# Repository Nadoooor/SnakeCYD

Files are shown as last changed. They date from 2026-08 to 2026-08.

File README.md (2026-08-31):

# SnakeCYD
--------------
<p align="center">
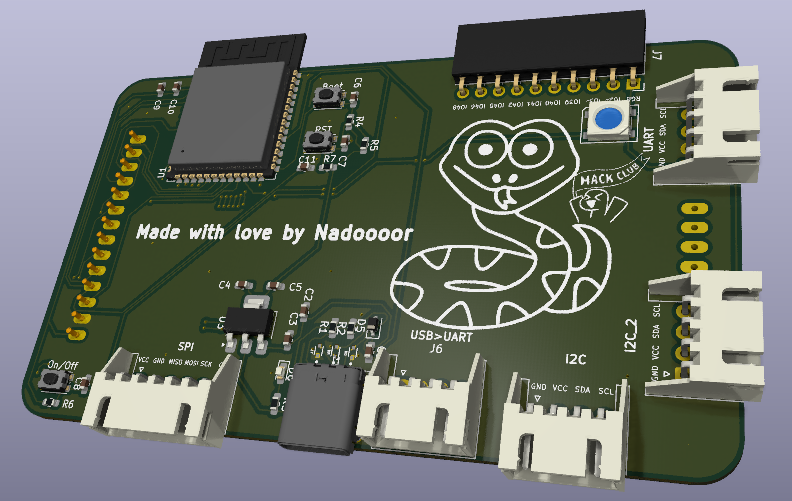
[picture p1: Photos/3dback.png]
Centered Image
  
</p>
--------------------------------

## Description:
SnakeCYD is a custom CYD, all in an PCB with snake slickscreen and with ESP32-s3 instead of a regular ESP32 chip.

## Why iam making this:
I was planning to get a CYD, but I got to know that it has a regular ESP32 on it instead of the S3, so i decided to make my own and add my snake slikscreen and also added bigger connectors for the wiring protocols and also some free pins.

## Featrues:

* Big JST connectors
* Free GPIO with PinSockets
* USB Type C
* Onboard Neopixel
* ESP32-S3 chip inside.

## Photos:

### PCB:
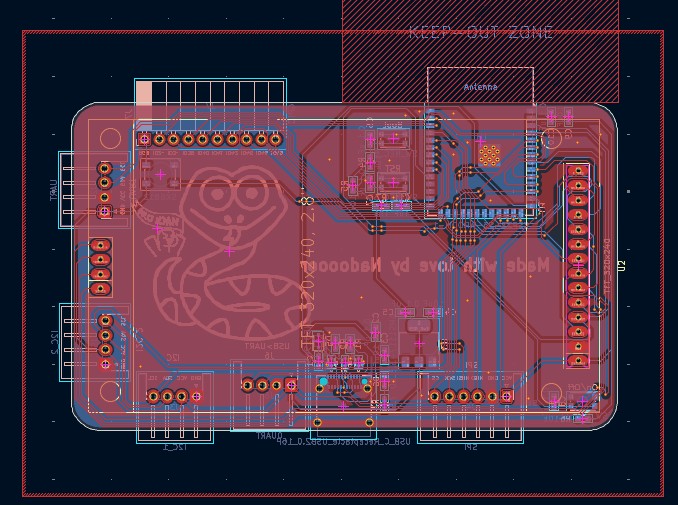
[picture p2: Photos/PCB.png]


### 3D PCB:
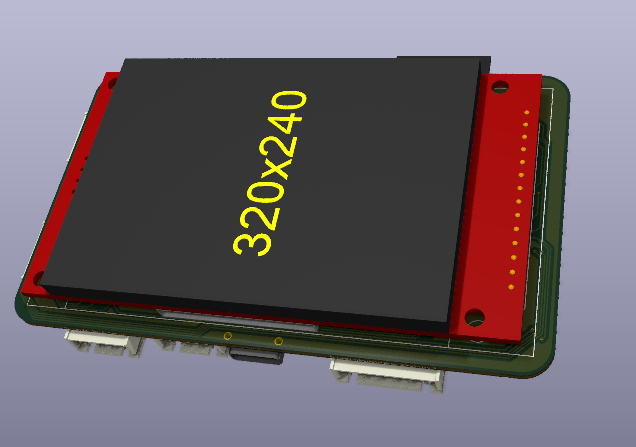
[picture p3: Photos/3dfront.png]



### Schematic:
#### First Page:
--------------------
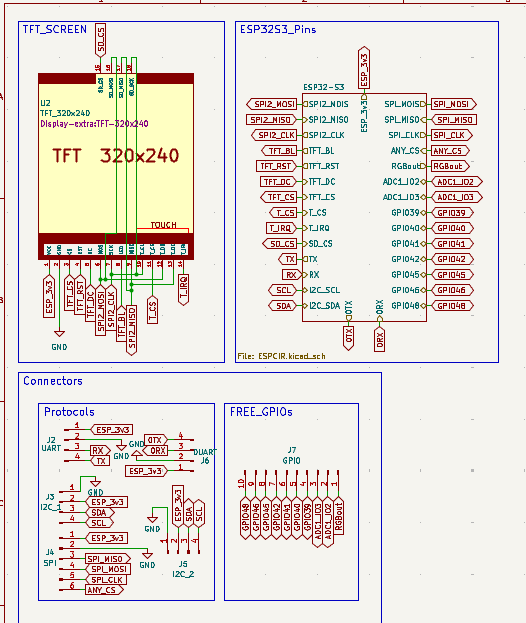
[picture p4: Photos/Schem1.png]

----------------------------
#### Second Page:
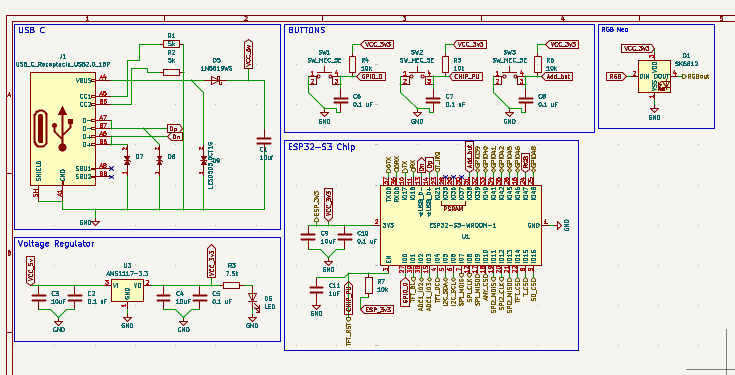
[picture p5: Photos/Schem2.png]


## Pinout:
| ESP32-S3 Pin Label | Signal / Net Name |
| :--- | :--- |
| **IO1** | `TFT_BL` |
| **IO4** | `TFT_DC` |
| **IO5** | `I2C_SDA` |
| **IO6** | `I2C_SCL` |
| **IO7** | `SPI_MOIS` |
| **IO8** | `SPI_CLK` |
| **IO9** | `SPI_MISO` |
| **IO10** | `ANY_CS` |
| **IO11** | `SPI2_MOIS` |
| **IO12** | `SPI2_CLK` |
| **IO13** | `SPI2_MISO` |
| **IO14** | `TFT_CS` |
| **IO15** | `T_CS` |
| **IO16** | `SD_CS` |
| **IO17** | `TX` |
| **IO18** | `RX` |
| **IO21** | `T_IRQ` |
| **TXD0** | `0TX` |
| **RXD0** | `0RX` |

## How to use:
1. Connect the SnakeCYD to you PC/Laptop.
2. Download the firmware source code you want to use.
3. Edit the pinout using the table above.
4. Build the firmware and flash it.
5. Enjoy.

## How to build:
1. Print the board.
2. Assemble all the components.
3. Enjoy.

# Made with ❤️, By Nadoooor

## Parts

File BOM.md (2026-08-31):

| Item | Store | Quantity | PPU | Price |
|---|---|---|-----|---|
| PCBA | JLCPCB | 1 | $94 | $94 |
| Shipping from JLCPCB | JLCPCB | 1 | $30 | $30 |
| TFT screen with SPI and touch 2.8in | [Aliexpress](https://ar.aliexpress.com/item/1005010008924503.html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) | 1 | $10 | $10 |
| Total | ~~~ | ~~~ | ~~~ | $134  |

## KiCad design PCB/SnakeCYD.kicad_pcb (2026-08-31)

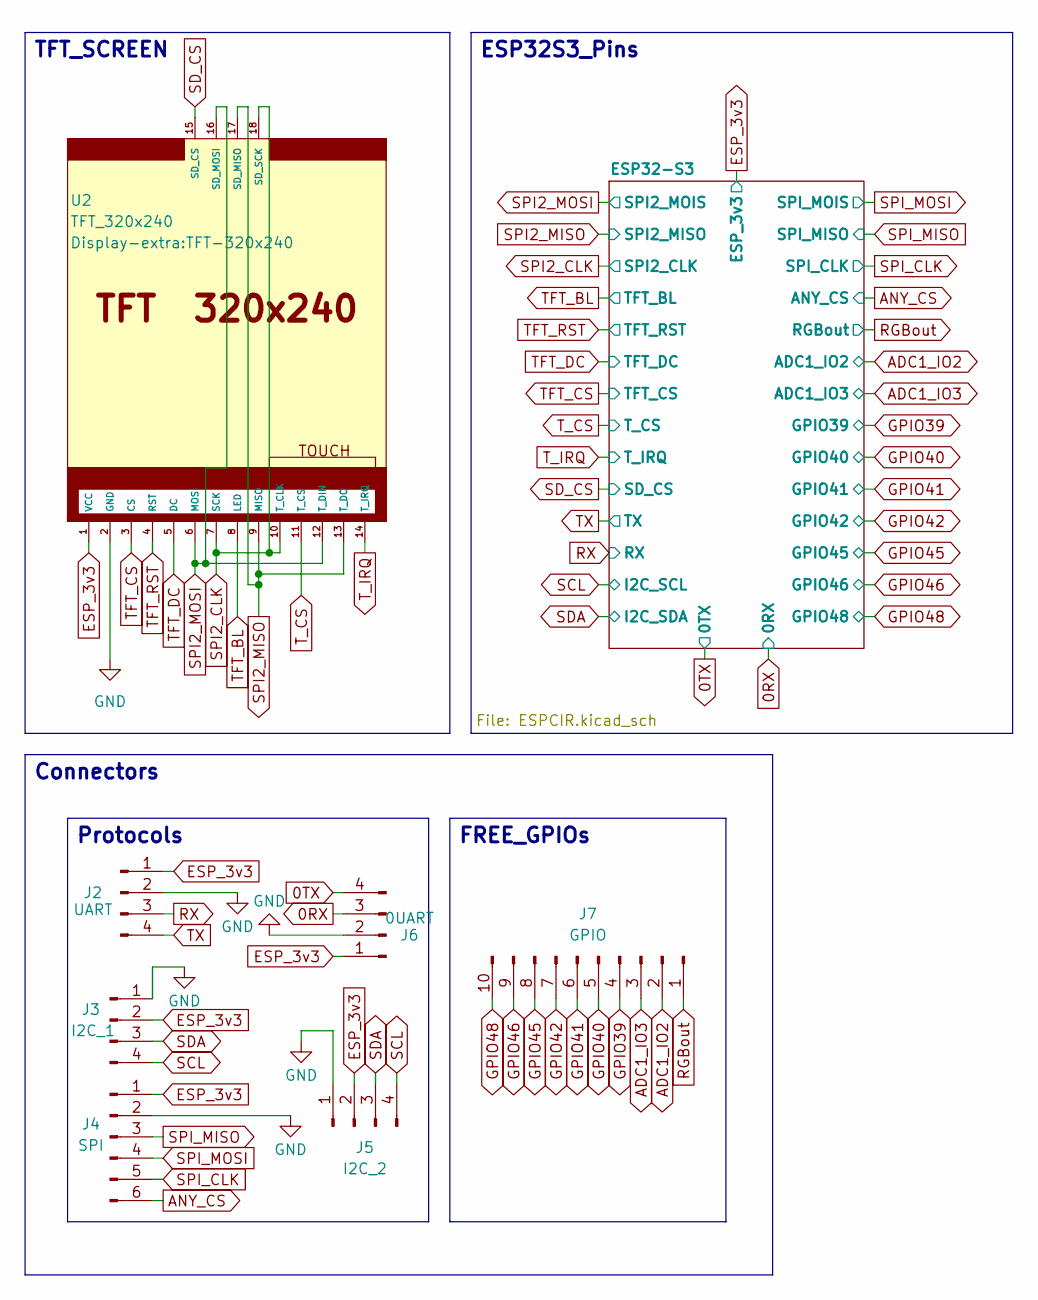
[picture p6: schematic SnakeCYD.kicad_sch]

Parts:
J2: UART; JST_XH_S4B-XH-A-1_1x04_P2.50mm_Horizontal
J3: I2C_1; JST_XH_S4B-XH-A-1_1x04_P2.50mm_Horizontal
J4: SPI; JST_XH_S6B-XH-A-1_1x06_P2.50mm_Horizontal
J5: I2C_2; JST_XH_S4B-XH-A-1_1x04_P2.50mm_Horizontal
J6: 0UART; JST_XH_S4B-XH-A-1_1x04_P2.50mm_Horizontal
J7: GPIO; PinSocket_1x10_P2.54mm_Horizontal
U2: TFT_320x240; TFT-320x240

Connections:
0RX: J6.3; also elsewhere on the board
0TX: J6.4; also elsewhere on the board
ADC1_IO2: J7.2; also elsewhere on the board
ADC1_IO3: J7.3; also elsewhere on the board
ANY_CS: J4.6; also elsewhere on the board
ESP_3v3: J2.1, J3.2, J4.1, J5.2, J6.1, U2.1 (VCC); also elsewhere on the board
GND: J2.2, J3.1, J4.2, J5.1, J6.2, U2.2 (GND); also elsewhere on the board
GPIO39: J7.4; also elsewhere on the board
GPIO40: J7.5; also elsewhere on the board
GPIO41: J7.6; also elsewhere on the board
GPIO42: J7.7; also elsewhere on the board
GPIO45: J7.8; also elsewhere on the board
GPIO46: J7.9; also elsewhere on the board
GPIO48: J7.10; also elsewhere on the board
RGBout: J7.1; also elsewhere on the board
RX: J2.3; also elsewhere on the board
SCL: J3.4, J5.4; also elsewhere on the board
SDA: J3.3, J5.3; also elsewhere on the board
SD_CS: U2.15 (SD_CS); also elsewhere on the board
SPI2_CLK: U2.7 (SCK), U2.10 (T_CLK), U2.18 (SD_SCK); also elsewhere on the board
SPI2_MISO: U2.9 (MISO), U2.13 (T_DO), U2.17 (SD_MISO); also elsewhere on the board
SPI2_MOSI: U2.6 (MOSI), U2.12 (T_DIN), U2.16 (SD_MOSI); also elsewhere on the board
SPI_CLK: J4.5; also elsewhere on the board
SPI_MISO: J4.3; also elsewhere on the board
SPI_MOSI: J4.4; also elsewhere on the board
TFT_BL: U2.8 (LED); also elsewhere on the board
TFT_CS: U2.3 (CS); also elsewhere on the board
TFT_DC: U2.5 (DC); also elsewhere on the board
TFT_RST: U2.4 (RST); also elsewhere on the board
TX: J2.4; also elsewhere on the board
T_CS: U2.11 (T_CS); also elsewhere on the board
T_IRQ: U2.14 (T_IRQ); also elsewhere on the board

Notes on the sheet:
TFT_SCREEN
Connectors
ESP32S3_Pins
Protocols
FREE_GPIOs

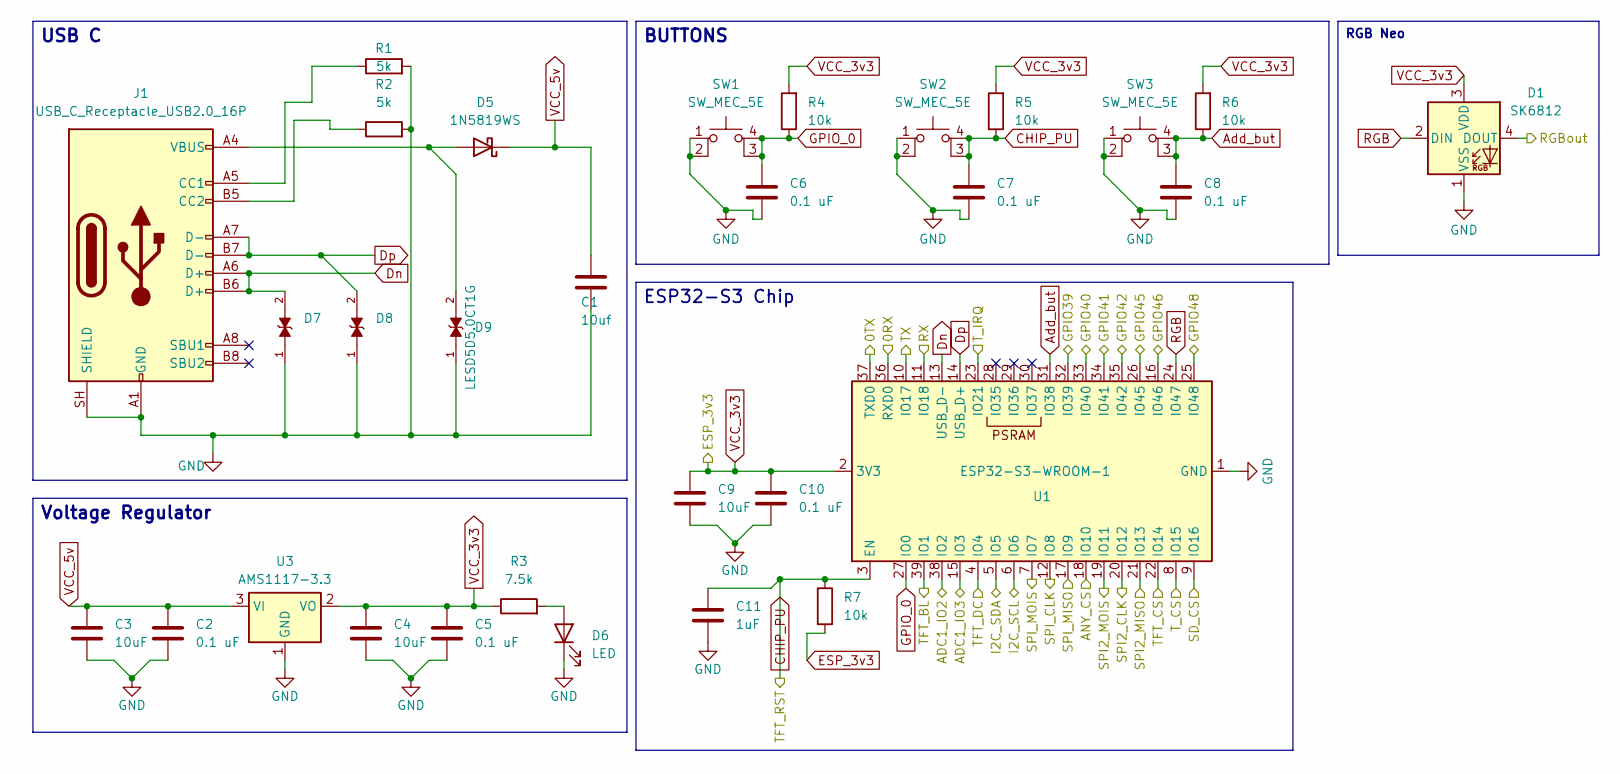
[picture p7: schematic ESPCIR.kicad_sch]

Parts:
C1: 10uf; C_0603_1608Metric_Pad1.08x0.95mm_HandSolder
C2, C5, C6, C7, C8, C10: 0.1 uF; C_0603_1608Metric_Pad1.08x0.95mm_HandSolder
C3, C4, C9: 10uF; C_0603_1608Metric_Pad1.08x0.95mm_HandSolder
C11: 1uF; C_0603_1608Metric_Pad1.08x0.95mm_HandSolder
D1: SK6812; LED_SK6812_PLCC4_5.0x5.0mm_P3.2mm
D5: 1N5819WS; D_SOD-323
D6: LED; LED_0603_1608Metric_Pad1.05x0.95mm_HandSolder
D7, D8, D9: LESD5D5.0CT1G; TVS_LESD5D5.0CT1G; PARTREV O
J1: USB_C_Receptacle_USB2.0_16P; USB_C_Receptacle_Amphenol_12401610E4-2A_CircularHoles
R1, R2: 5k; R_0603_1608Metric_Pad0.98x0.95mm_HandSolder
R3: 7.5k; R_0603_1608Metric_Pad0.98x0.95mm_HandSolder
R4, R5, R6, R7: 10k; R_0603_1608Metric_Pad0.98x0.95mm_HandSolder
SW1, SW2, SW3: SW_MEC_5E; SW_Push_1P1T_NO_CK_KMR2
U1: ESP32-S3-WROOM-1
U3: AMS1117-3.3; SOT-223-3_TabPin2

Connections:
0RX: U1.36 (RXD0); also elsewhere on the board
0TX: U1.37 (TXD0); also elsewhere on the board
ADC1_IO2: U1.38 (IO2); also elsewhere on the board
ADC1_IO3: U1.15 (IO3); also elsewhere on the board
ANY_CS: U1.18 (IO10); also elsewhere on the board
Add_but: C8.1, R6.1, SW3.3 (K), SW3.4 (A), U1.31 (IO38); also elsewhere on the board
Dn: D7.2, J1.A6 (D+), J1.B6 (D+), U1.13 (USB_D-)
Dp: D8.2, J1.A7 (D-), J1.B7 (D-), U1.14 (USB_D+)
ESP_3v3: C4.1, C5.1, C9.1, C10.1, D1.3 (VDD), R3.1, R4.2, R5.2, R6.2, R7.2, U1.2 (3V3), U3.2 (VO); also elsewhere on the board
GND: C1.2, C2.2, C3.2, C4.2, C5.2, C6.2, C7.2, C8.2, C9.2, C10.2, C11.2, D1.1 (VSS), D6.1 (K), D7.1, D8.1, D9.1, J1.A1 (GND), J1.A12 (GND), J1.B1 (GND), J1.B12 (GND), J1.SH (SHIELD), R1.2, R2.2, SW1.1, SW1.2, SW2.1, SW2.2, SW3.1, SW3.2, U1.1 (GND), U1.40 (GND), U1.41 (GND), U3.1 (GND); also elsewhere on the board
GPIO39: U1.32 (IO39); also elsewhere on the board
GPIO40: U1.33 (IO40); also elsewhere on the board
GPIO41: U1.34 (IO41); also elsewhere on the board
GPIO42: U1.35 (IO42); also elsewhere on the board
GPIO45: U1.26 (IO45); also elsewhere on the board
GPIO46: U1.16 (IO46); also elsewhere on the board
GPIO48: U1.25 (IO48); also elsewhere on the board
GPIO_0: C6.1, R4.1, SW1.3 (K), SW1.4 (A), U1.27 (IO0); also elsewhere on the board
unnamed: D5.2 (A), D9.2, J1.A4 (VBUS), J1.A9 (VBUS), J1.B4 (VBUS), J1.B9 (VBUS)
unnamed: D6.2 (A), R3.2
unnamed: J1.A5 (CC1), R1.1
unnamed: J1.B5 (CC2), R2.1
RGB: D1.2 (DIN), U1.24 (IO47)
RGBout: D1.4 (DOUT); also elsewhere on the board
RX: U1.11 (IO18); also elsewhere on the board
SCL: U1.6 (IO6); also elsewhere on the board
SDA: U1.5 (IO5); also elsewhere on the board
SD_CS: U1.9 (IO16); also elsewhere on the board
SPI2_CLK: U1.20 (IO12); also elsewhere on the board
SPI2_MISO: U1.21 (IO13); also elsewhere on the board
SPI2_MOSI: U1.19 (IO11); also elsewhere on the board
SPI_CLK: U1.12 (IO8); also elsewhere on the board
SPI_MISO: U1.17 (IO9); also elsewhere on the board
SPI_MOSI: U1.7 (IO7); also elsewhere on the board
TFT_BL: U1.39 (IO1); also elsewhere on the board
TFT_CS: U1.22 (IO14); also elsewhere on the board
TFT_DC: U1.4 (IO4); also elsewhere on the board
TFT_RST: C7.1, C11.1, R5.1, R7.1, SW2.3 (K), SW2.4 (A), U1.3 (EN); also elsewhere on the board
TX: U1.10 (IO17); also elsewhere on the board
T_CS: U1.8 (IO15); also elsewhere on the board
T_IRQ: U1.23 (IO21); also elsewhere on the board
VCC_5v: C1.1, C2.1, C3.1, D5.1 (K), U3.3 (VI)

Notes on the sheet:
USB C
ESP32-S3 Chip
RGB Neo
BUTTONS
Voltage Regulator

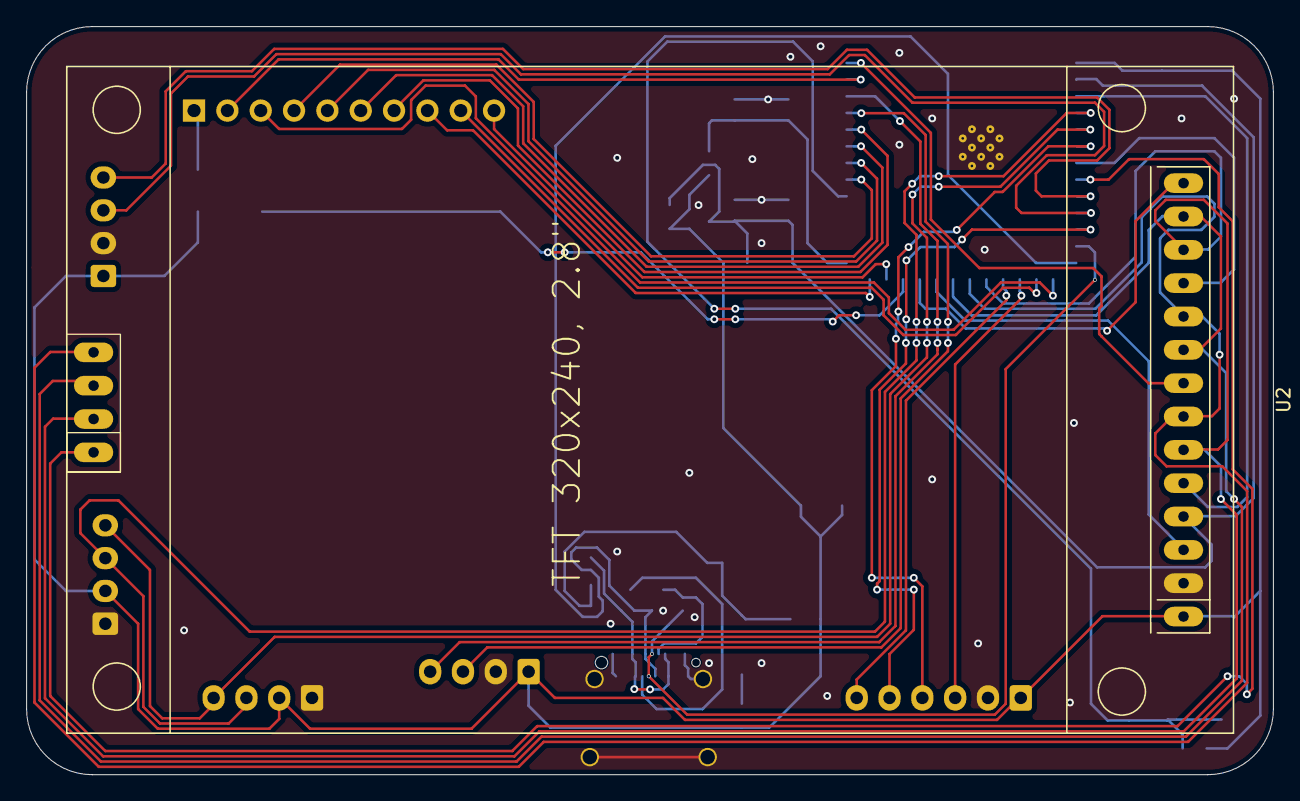
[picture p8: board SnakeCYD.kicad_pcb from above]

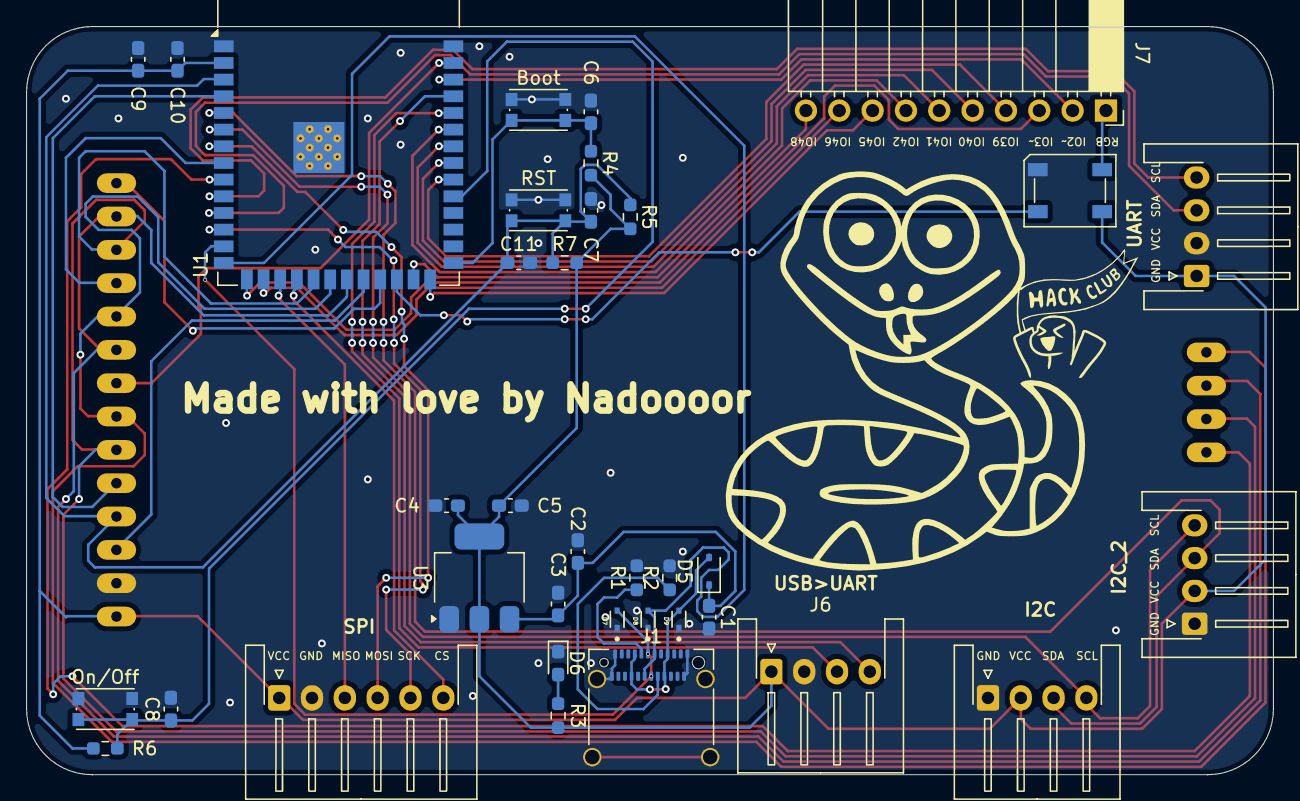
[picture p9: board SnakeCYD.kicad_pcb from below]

Board: 2 copper layers, 95.0 x 57.0 mm, 37 parts (36 on the bottom side), 42 nets.

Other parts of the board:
Boot: SW_MEC_5E; SW_Push_1P1T_NO_CK_KMR2
On/Off: SW_MEC_5E; SW_Push_1P1T_NO_CK_KMR2
RST: SW_MEC_5E; SW_Push_1P1T_NO_CK_KMR2

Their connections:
Add_but: On/Off.3 (K), On/Off.4 (A); also elsewhere on the board
GND: Boot.1, Boot.2, On/Off.1, On/Off.2, RST.1, RST.2; also elsewhere on the board
GPIO_0: Boot.3 (K), Boot.4 (A); also elsewhere on the board
TFT_RST: RST.3 (K), RST.4 (A); also elsewhere on the board

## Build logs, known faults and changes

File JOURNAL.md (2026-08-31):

# SnakeCYD (Journal)
## Description:
SnakeCYD is a custom CYD, all in an PCB with snake slickscreen and with ESP32-s3 instead of a regular ESP32 chip.

## Entry 1
- Date 29/08/2026

### Content:
uhh this would take too long to write

ok i'll try my best

Hmm, well i decided to make a CYD clone with my changes and with an ESP32-s3 instead of the regular one, So i started by making my mind map and think about all the things i can add, 

All the things even if i will add them in different versions not only the first version.

and i got many, so i made some of them in this version

Well starting with the schematic ofcourse.

Well, in this time i wanted to learn how to use more than one Schematic page.

So i decided to make all the PCB in a page, and the other things like the display and the connectors in a page.

Starting with the ESP32-s3 page, i searched the internet and found a blog or artical talking about making a custom ESP32.

So i found the scchemtic in it and found the important parts and found that i don't need to make the Programmer circuit as the ESP32 has a built in USB and programmer.

So i only made the USB type C connector along the Voltage regulation circuit and the buttons and the chip itself.

and ended up with this.    <br>
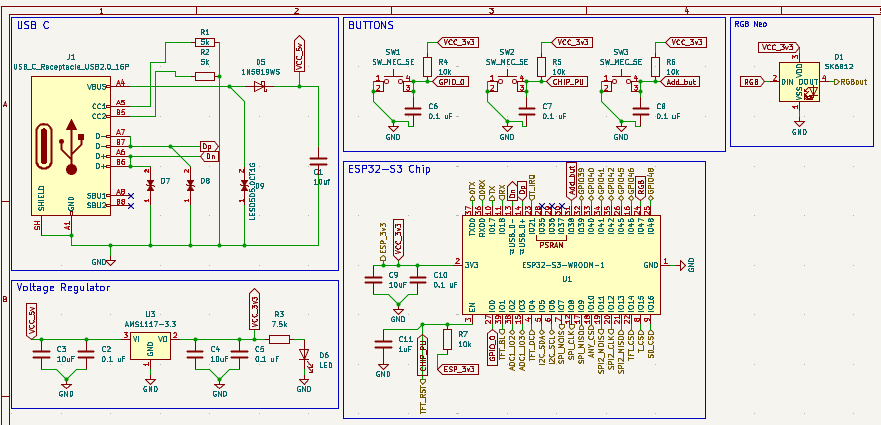
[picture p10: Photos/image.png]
 
<br>
and yeah i also added the neo pixel and connected its Dout to to a free pin so i can take the data from it to any other neo strip.

After making this ESP32-s3 circuit i went to the other page and added the connectors and also the TFT itself.

And then gave each one's pins global labels.

and after finished them. i went to the ESP page and started making many page labels so i can take these pins out of the page to the main page where the connectors and the TFT.

And i ended up making the main page like this. 

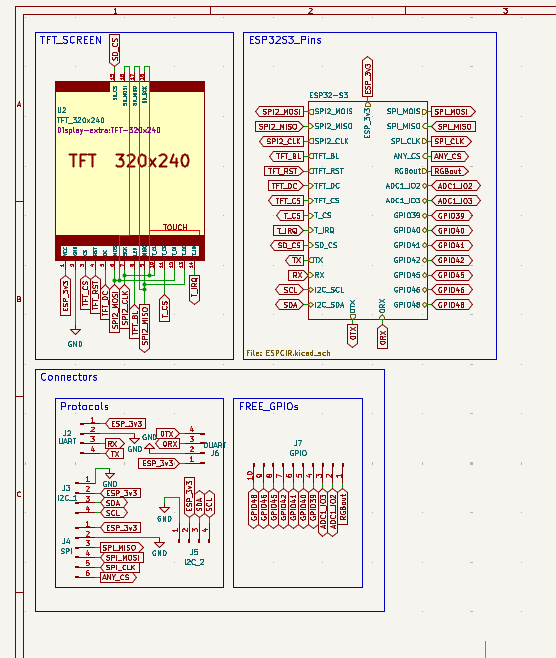
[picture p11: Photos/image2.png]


After that, i finished all the schematic, but yeah i found a problem while iam making the TFT, well i mistakenly saw an arduino circuit connected to this TFT module, but it had many pull resistors which i don't need with ESP, so i removed them again.

After that i assigned all the components to the right footprints, i found them all in kicad but one footprint, which was the LESD5D5.0CT1G, so i downloaded it and added it.

After that, i went to the PCB desinging.

And got the screen and centered it and drew a rectangle around it that is 3mm bigger than it.

i then rounded the corners and started spreading out all the components in good places relativly to each other. like the voltage regulation circuit near the Type C and so on.

And i got it like that.

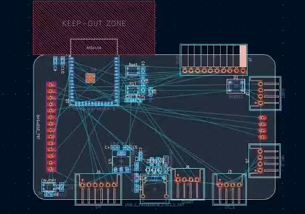
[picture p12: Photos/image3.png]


I then traced some of the components but i need to sleep so i closed the recording and said to continue atfter i wake up.
## Recording link:
https://lapse.hackclub.com/timelapse/Q-Om9-Dlgel0

## Entry 2
- Date: 31/08/2026

### Content:

Iam back, i had to go to somewhere yesterday so i didn't work.

but hey i ended it all now.

OK, i started tracing all the remaining components, well iam gonna to say two things i made while iam tracing which was so funny and i liked them

First i tried to trace all the SMD compnents from the back side so i can leave space for all the THT components from the top side and this was the best thing i've ever thinked about.

it was so easier to trace the THT from the Top layer instead of thet bottom.

to achieve that with the ESP32 smd chip, i made vias beside all the pins i need to connect the THT components to. so it ended up like this.

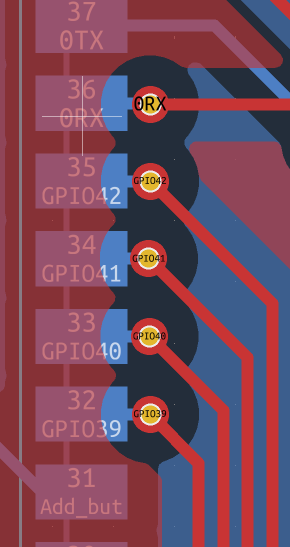
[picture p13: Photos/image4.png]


and also when ever i meet a trace that i need to walk through it, i made like briges for it like that.

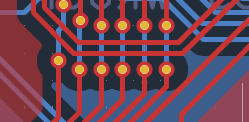
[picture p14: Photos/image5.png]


after finishing that all, i started writing the pin out on all the connnectors so it can be easy for anyone to understand.

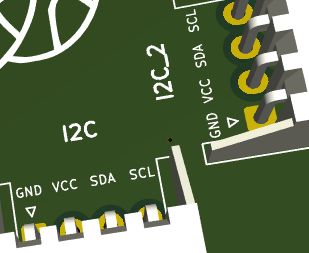
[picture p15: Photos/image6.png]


And also added my touch to it, like my Snake silkscreen and "Made with Love by Nadoooor"

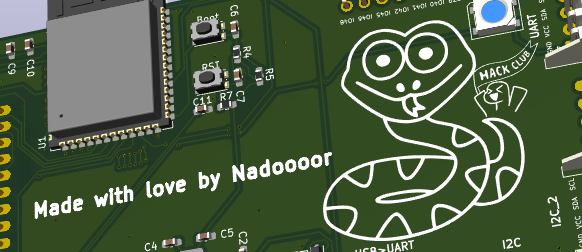
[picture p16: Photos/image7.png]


And yeah that's it, i finished all the PCB, and also exported it to gerber files.



### Recording link:
https://lapse.hackclub.com/timelapse/JCPJE0gUIzQD

## Thanks so much for reading this, bro. ❤️

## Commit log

2026-08-29 Added the Type C circuit and wired it (Schem)
    [ESPCIR.kicad_sch, SnakeCYD.kicad_pcb, SnakeCYD.kicad_sch]
2026-08-29 Wired Buttons, Voltage regulator, RGB neopixel
    [ESPCIR.kicad_sch]
2026-08-29 Wired the tft screen (Schem)
    [ESPCIR.kicad_sch, SnakeCYD.kicad_sch]
2026-08-29 Assigned all the avaliable pins from the esp32 s3 gpio to labels (Schem)
    [ESPCIR.kicad_sch, SnakeCYD.kicad_sch]
2026-08-29 (Likely finished the Schem) Wired all the connectors and esp pins
    [ESPCIR.kicad_sch, SnakeCYD.kicad_sch]
2026-08-29 Fully Finshed the schem
    [ESPCIR.kicad_sch, SnakeCYD.kicad_pcb, SnakeCYD.kicad_sch]
2026-08-29 well placed all the compnents in their places (PCB)
    [ESPCIR.kicad_sch, SnakeCYD.kicad_pcb]
2026-08-29 Traced most of the components (PCB)
    [SnakeCYD.kicad_pcb]
2026-08-31 Finished tracing and fixing all the PCB
    [SnakeCYD.kicad_pcb]
2026-08-31 Slikscreen labeled all the pins
    [SnakeCYD.kicad_pcb]
2026-08-31 add the files into a folder to organize the repo
    [ESPCIR.kicad_sch, SnakeCYD.kicad_pcb, SnakeCYD.kicad_sch]
2026-08-31 Wrote the BOM
    [SnakeCYD.kicad_pcb]
